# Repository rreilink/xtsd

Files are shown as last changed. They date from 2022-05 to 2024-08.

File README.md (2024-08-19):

XTSD 
====

XTSD is an ISA card that adds an SD-card slot to old PCs using an ISA interface. This project is work in progress.

Repo structure
--------------

| folder | description |
|---|---|
|hardware| Schematic and PCB design in KiCAD |
|hardware-output | Schematic as PDF and Gerber layout files for ordering the PCB |
|GAL | Source and JEDEC binary file for the programmable logic chip U6 (ATF22V10) |

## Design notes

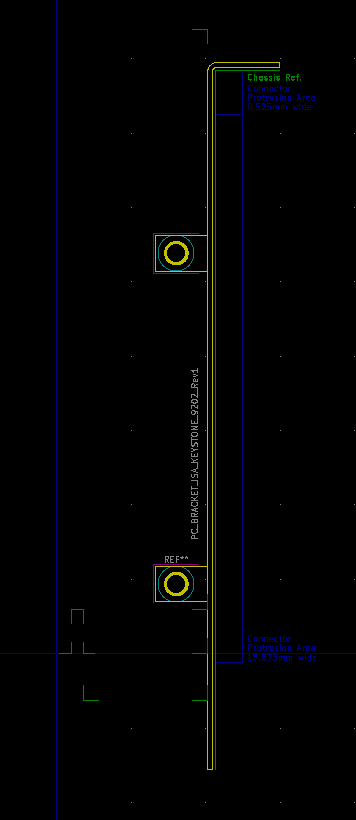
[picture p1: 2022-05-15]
Kicad_Misc-master/Footprints/PC_Bracket_ISA_Keystone_9202/Images/Keystone_9202_Rev1.PNG

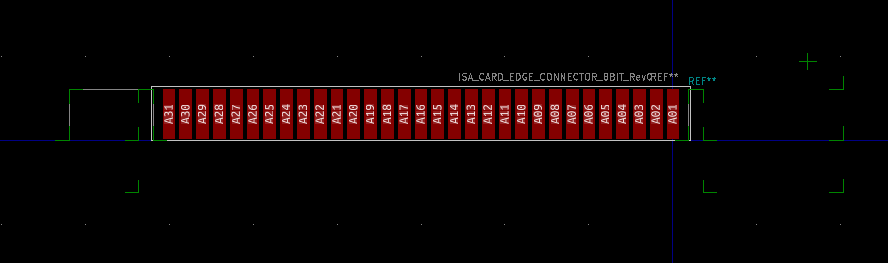
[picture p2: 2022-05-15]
Kicad_Misc-master/Footprints/ISA_Card_Edge_Connector_8bit/Images/ISA_Card_Edge_Connector_8bit_Rev0.PNG

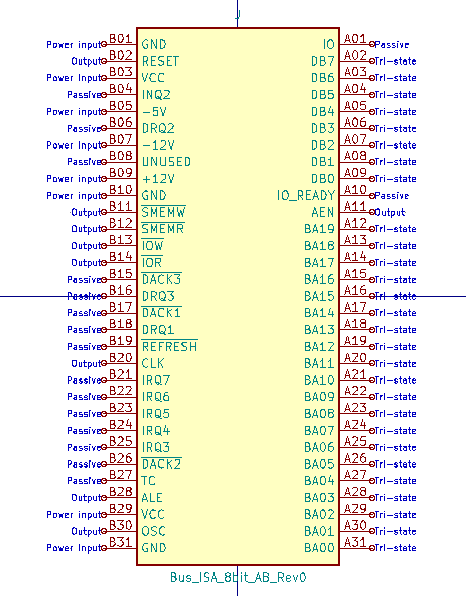
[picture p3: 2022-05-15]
Kicad_Misc-master/Symbols/Bus_ISA_8bit_AB/Images/Bus_ISA_8bit_AB_Rev0.PNG

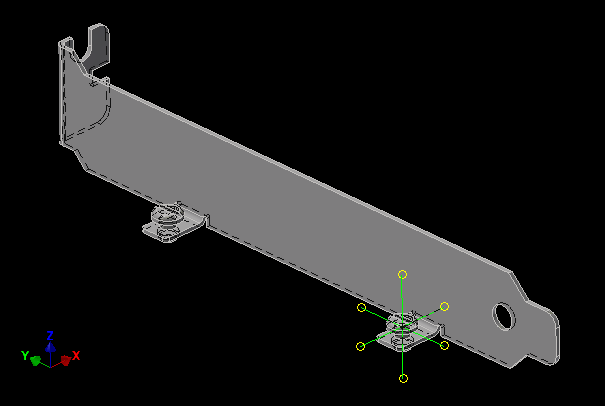
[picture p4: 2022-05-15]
Kicad_Misc-master/3D_Models/Keystone_9202/Images/Keystone_9202_3D_Rev0_1.PNG

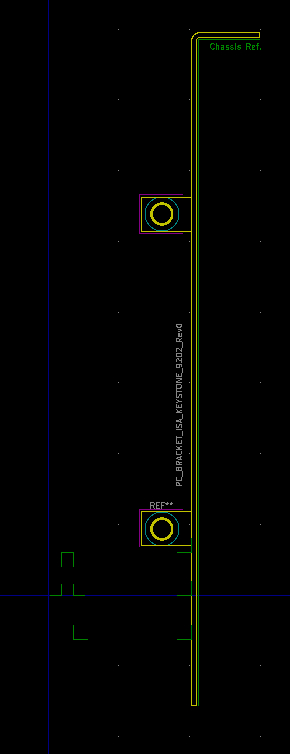
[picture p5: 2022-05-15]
Kicad_Misc-master/Footprints/PC_Bracket_ISA_Keystone_9202/Images/Keystone_9202_Rev0.PNG

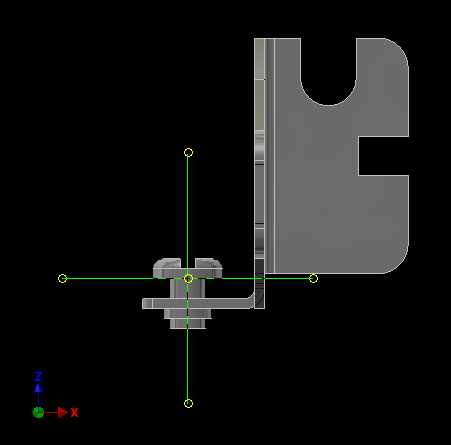
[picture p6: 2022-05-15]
Kicad_Misc-master/3D_Models/Keystone_9202/Images/Keystone_9202_3D_Rev0_2.PNG

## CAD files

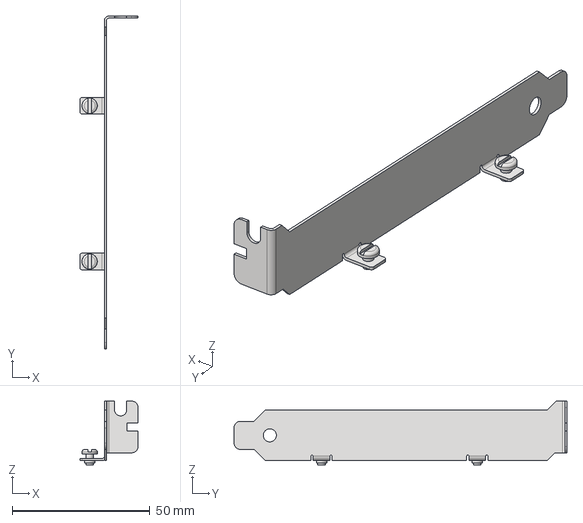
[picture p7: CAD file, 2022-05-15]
Kicad_Misc-master/3D_Models/Keystone_9202/Keystone_9202_Blank.stp
21.1 x 120.8 x 23.2 mm

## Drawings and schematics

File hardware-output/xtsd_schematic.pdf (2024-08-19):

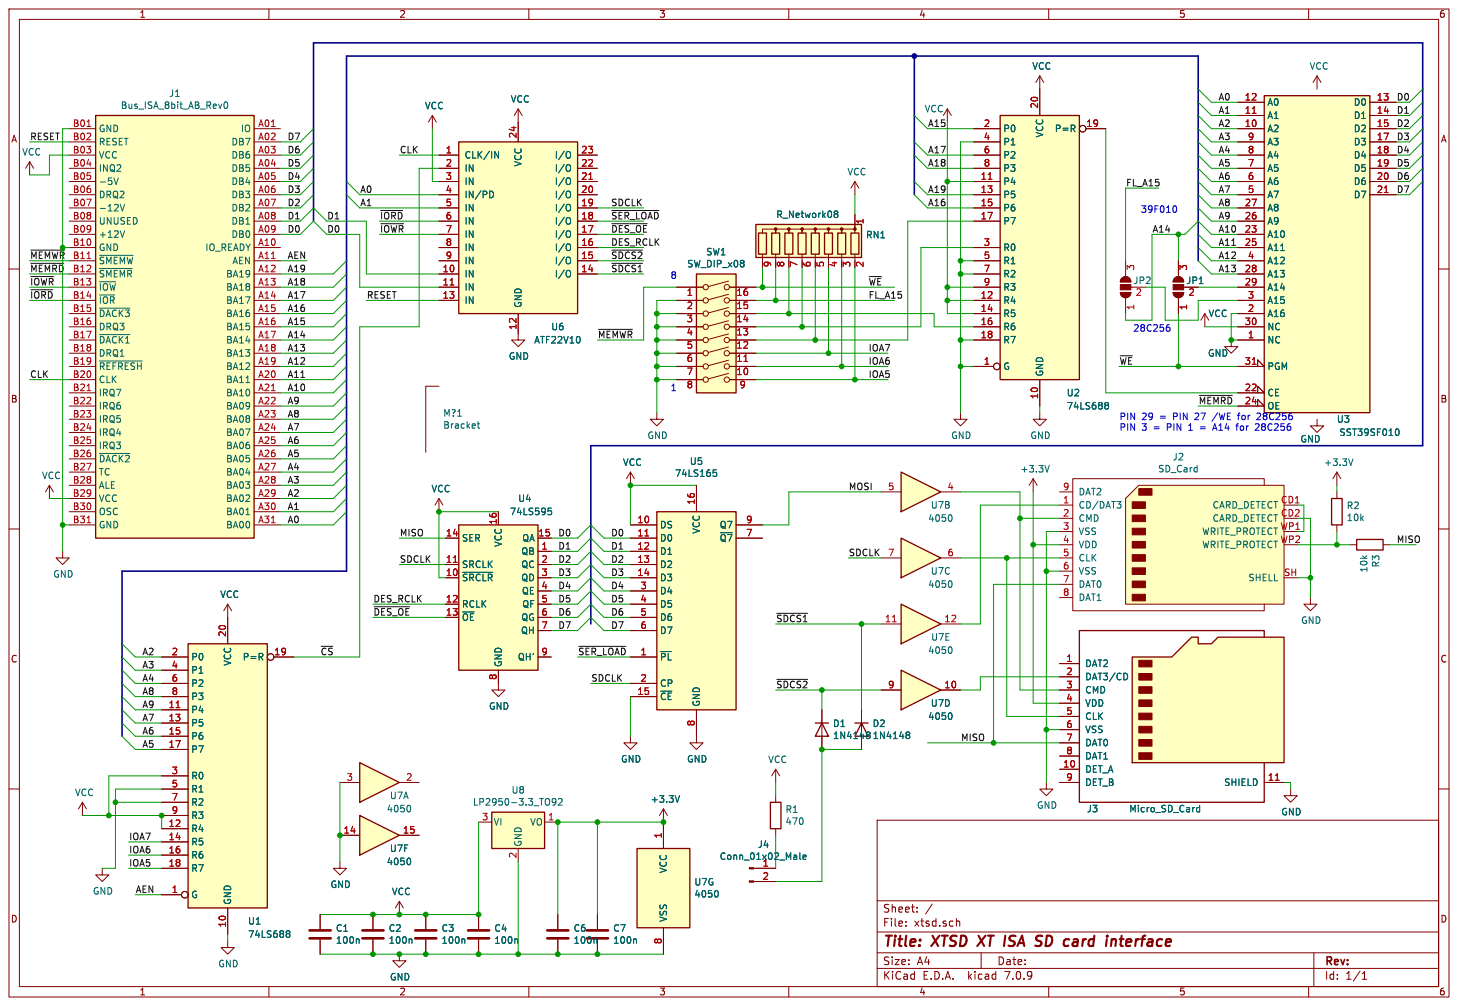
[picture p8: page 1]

J1 Bus_ISA_8bit_AB_Rev0 VCC
IO_READY A10 AEN A11 BA19 A12 BA18 A13 BA17 A14 BA16 A15 BA15 A16 BA14 A17 BA13 A18 BA12 A19 BA11 A20 BA10 A21 BA09 A22 BA08 A23 BA07 A24 BA06 A25 BA05 A26 BA04 A27 BA03 A28 BA02 A29 BA01 A30 BA00 A31 GND B01 RESET B02 VCC B03
-12V B07 UNUSED B08 +12V B09 GND B10 ~{SMEMW} B11 ~{SMEMR} B12 ~{IOW} B13 ~{IOR} B14 ~{DACK3} B15 DRQ3 B16 ~{DACK1} B17 DRQ1 B18 ~{REFRESH} B19 CLK B20

File: xtsd.sch Sheet: /
Id: 1/1 Title: XTSD XT ISA SD card interface

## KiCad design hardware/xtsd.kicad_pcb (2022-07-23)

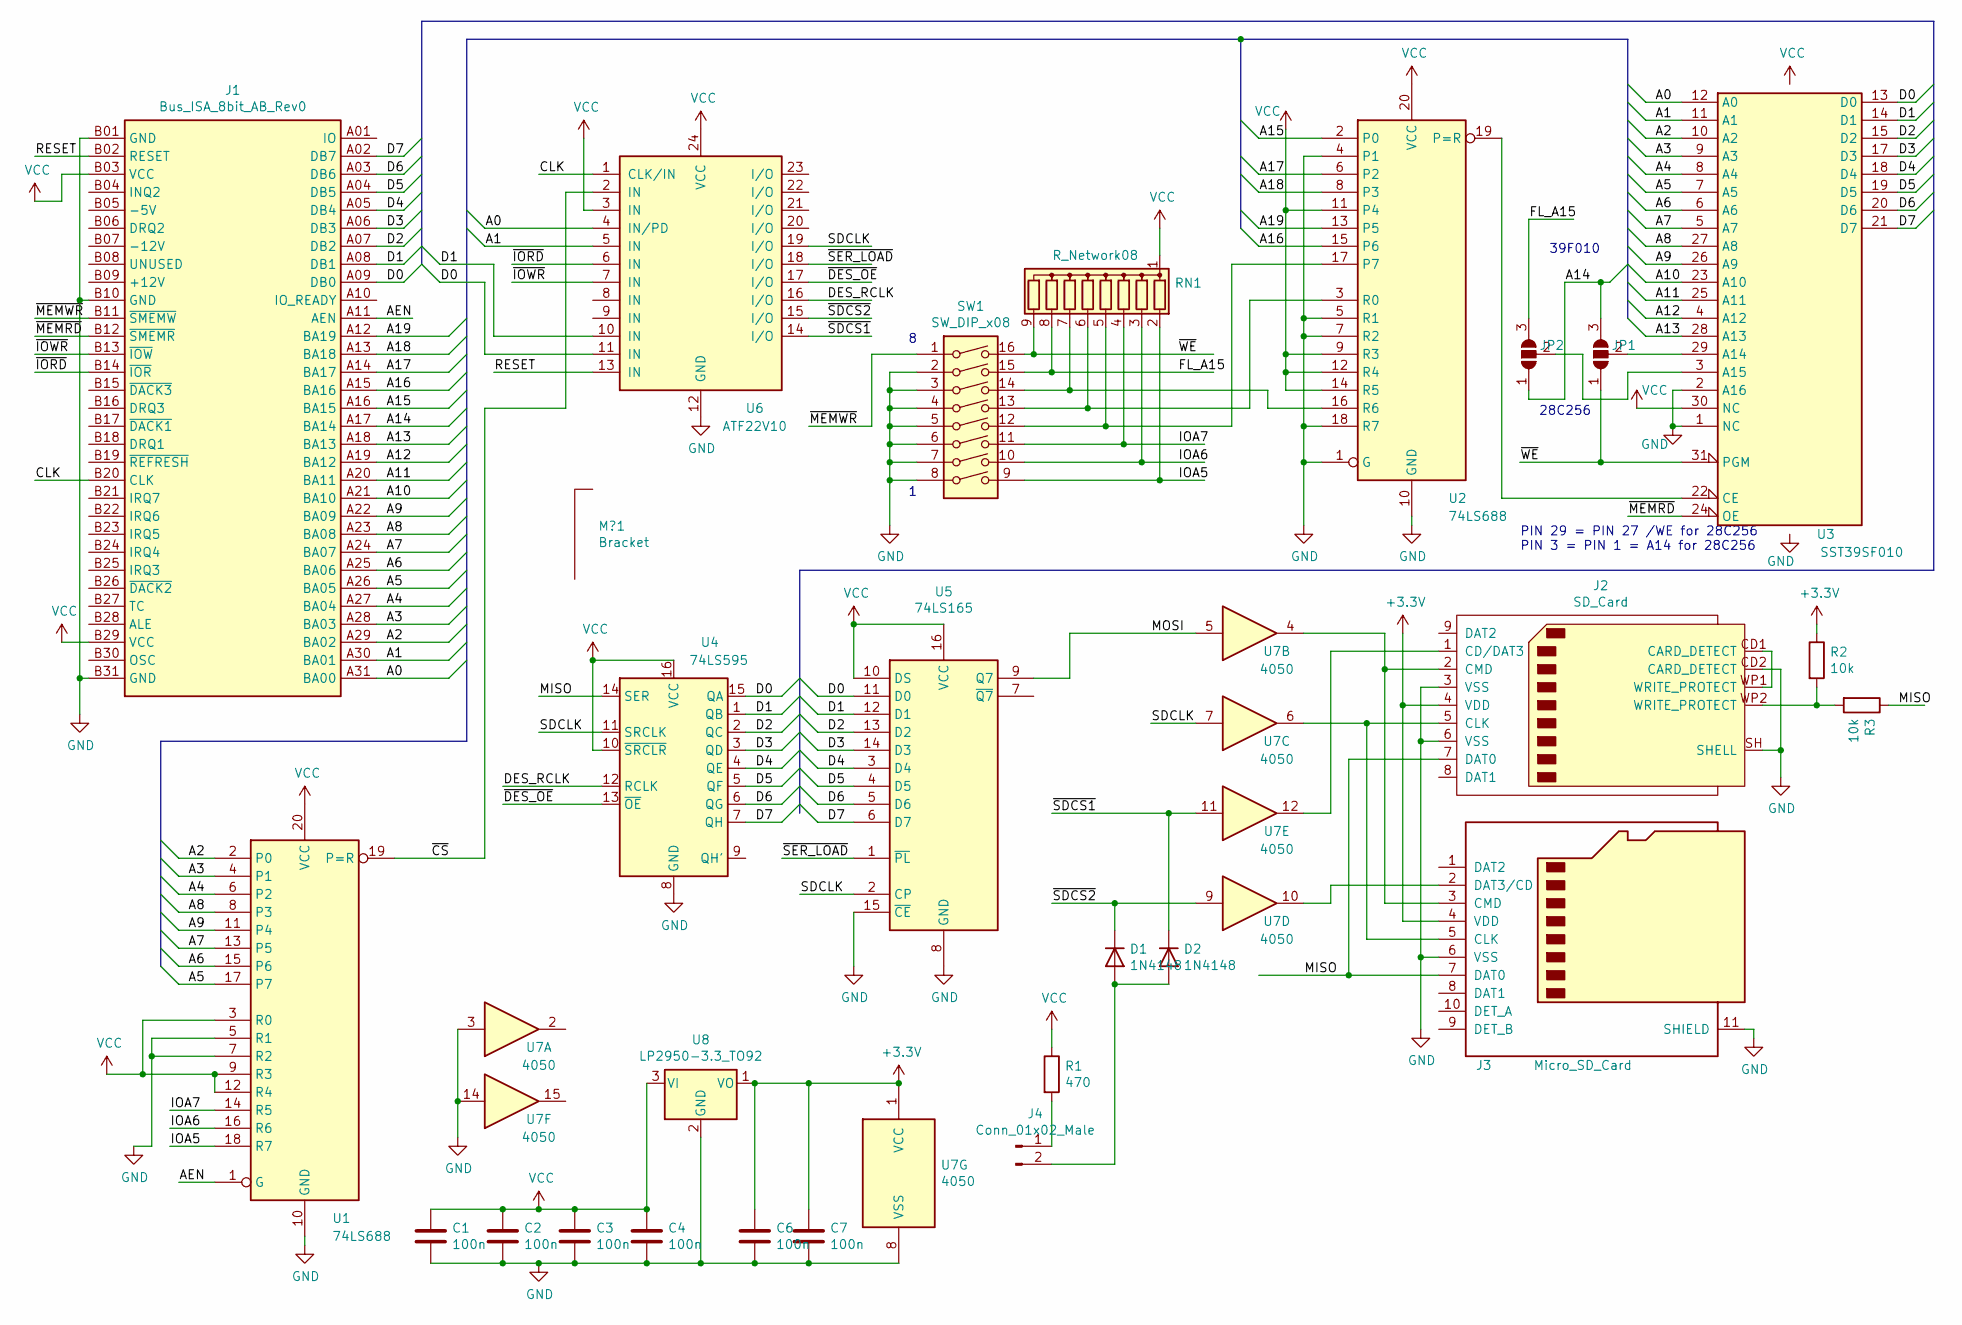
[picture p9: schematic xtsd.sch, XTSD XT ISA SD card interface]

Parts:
C1, C2, C3, C4, C6, C7: 100n; C_Disc_D4.3mm_W1.9mm_P5.00mm
D1, D2: 1N4148; D_DO-35_SOD27_P7.62mm_Horizontal
J1: Bus_ISA_8bit_AB_Rev0; ISA_CARD_EDGE_CONNECTOR_8BIT_Rev1
J2: SD_Card; Molex_503500-0991
J3: Micro_SD_Card; microSD_HC_Molex_104031-0811; Farnell 2678573
J4: Conn_01x02_Male; PinHeader_1x02_P2.54mm_Horizontal
JP1, JP2: SolderJumper_3_Open; SolderJumper-3_P2.0mm_Open_TrianglePad1.0x1.5mm_NumberLabels
M?1: Bracket; PC_BRACKET_ISA_KEYSTONE_9202_Rev1
R1: 470; R_Axial_DIN0207_L6.3mm_D2.5mm_P7.62mm_Horizontal
R2, R3: 10k; R_Axial_DIN0207_L6.3mm_D2.5mm_P7.62mm_Horizontal
RN1: R_Network08; R_Array_SIP9
SW1: SW_DIP_x08; SW_DIP_SPSTx08_Slide_9.78x22.5mm_W7.62mm_P2.54mm
U1, U2: 74LS688; DIP-20_W7.62mm_LongPads
U3: SST39SF010; DIP-32_W15.24mm_Socket_LongPads
U4: 74LS595; DIP-16_W7.62mm_LongPads
U5: 74LS165; DIP-16_W7.62mm_LongPads
U6: ATF22V10; DIP-24_W7.62mm_Socket_LongPads
U7: 4050; DIP-16_W7.62mm_LongPads
U8: LP2950-3.3_TO92; TO-92_Inline

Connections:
+3V3: C6.1, C7.1, J2.4 (VDD), J3.4 (VDD), R2.1, U7.1 (VCC), U8.1 (VO)
/A0: J1.A31 (BA00), U3.12 (A0), U6.4 (IN/PD)
/A1: J1.A30 (BA01), U3.11 (A1), U6.5 (IN)
/A2: J1.A29 (BA02), U1.2 (P0), U3.10 (A2)
/A3: J1.A28 (BA03), U1.4 (P1), U3.9 (A3)
/A4: J1.A27 (BA04), U1.6 (P2), U3.8 (A4)
/A5: J1.A26 (BA05), U1.17 (P7), U3.7 (A5)
/A6: J1.A25 (BA06), U1.15 (P6), U3.6 (A6)
/A7: J1.A24 (BA07), U1.13 (P5), U3.5 (A7)
/A8: J1.A23 (BA08), U1.8 (P3), U3.27 (A8)
/A9: J1.A22 (BA09), U1.11 (P4), U3.26 (A9)
/A10: J1.A21 (BA10), U3.23 (A10)
/A11: J1.A20 (BA11), U3.25 (A11)
/A12: J1.A19 (BA12), U3.4 (A12)
/A13: J1.A18 (BA13), U3.28 (A13)
/A14: J1.A17 (BA14), JP1.3 (B), JP2.1 (A)
/A15: J1.A16 (BA15), U2.2 (P0)
/A16: J1.A15 (BA16), U2.15 (P6)
/A17: J1.A14 (BA17), U2.6 (P2)
/A18: J1.A13 (BA18), U2.8 (P3)
/A19: J1.A12 (BA19), U2.13 (P5)
/AEN: J1.A11 (AEN), U1.1 (G)
/CLK: J1.B20 (CLK), U6.1 (CLK/IN)
/D0: J1.A09 (DB0), U3.13 (D0), U4.15 (QA), U5.11 (D0), U6.11 (IN)
/D1: J1.A08 (DB1), U3.14 (D1), U4.1 (QB), U5.12 (D1), U6.10 (IN)
/D2: J1.A07 (DB2), U3.15 (D2), U4.2 (QC), U5.13 (D2)
/D3: J1.A06 (DB3), U3.17 (D3), U4.3 (QD), U5.14 (D3)
/D4: J1.A05 (DB4), U3.18 (D4), U4.4 (QE), U5.3 (D4)
/D5: J1.A04 (DB5), U3.19 (D5), U4.5 (QF), U5.4 (D5)
/D6: J1.A03 (DB6), U3.20 (D6), U4.6 (QG), U5.5 (D6)
/D7: J1.A02 (DB7), U3.21 (D7), U4.7 (QH), U5.6 (D7)
/DES_RCLK: U4.12 (RCLK), U6.16 (I/O)
/FL_A15: JP2.3 (B), RN1.8 (R7), SW1.15
/IOA5: RN1.2 (R1), SW1.9, U1.18 (R7)
/IOA6: RN1.3 (R2), SW1.10, U1.16 (R6)
/IOA7: RN1.4 (R3), SW1.11, U1.14 (R5)
/MISO: J2.7 (DAT0), J3.7 (DAT0), R3.1, U4.14 (SER)
/MOSI: U5.9 (Q7), U7.5
/RESET: J1.B02 (RESET), U6.13 (IN)
/SDCLK: U4.11 (SRCLK), U5.2 (CP), U6.19 (I/O), U7.7
/~CS~: U1.19 (P=R), U6.2 (IN)
/~DES_OE~: U4.13 (~OE), U6.17 (I/O)
/~IORD~: J1.B14 (~IOR), U6.6 (IN)
/~IOWR~: J1.B13 (~IOW), U6.7 (IN)
/~MEMRD~: J1.B12 (~SMEMR), U3.24 (OE)
/~MEMWR~: J1.B11 (~SMEMW), SW1.1
/~SDCS1~: D2.1 (K), U6.14 (I/O), U7.11
/~SDCS2~: D1.1 (K), U6.15 (I/O), U7.9
/~SER_LOAD~: U5.1 (~PL), U6.18 (I/O)
/~WE~: JP1.1 (A), RN1.9 (R8), SW1.16, U3.31 (PGM)
GND: C1.2, C2.2, C3.2, C4.2, C6.2, C7.2, J1.B01 (GND), J1.B10 (GND), J1.B31 (GND), J2.3 (VSS), J2.6 (VSS), J2.CD2 (CARD_DETECT), J2.SH (SHELL), J3.6 (VSS), J3.11 (SHIELD), SW1.2, SW1.3, SW1.4, SW1.5, SW1.6, SW1.7, SW1.8, U1.5 (R1), U1.7 (R2), U1.10 (GND), U2.1 (G), U2.4 (P1), U2.5 (R1), U2.7 (R2), U2.10 (GND), U2.18 (R7), U3.1 (NC), U3.2 (A16), U3.16 (GND), U4.8 (GND), U5.8 (GND), U5.15 (~CE), U6.12 (GND), U7.3, U7.8 (VSS), U7.14, U8.2 (GND)
unnamed: D1.2 (A), D2.2 (A), J4.2
unnamed: J2.1 (CD/DAT3), U7.12
unnamed: J2.2 (CMD), J3.3 (CMD), U7.4
unnamed: J2.5 (CLK), J3.5 (CLK), U7.6
unnamed: J2.CD1 (CARD_DETECT), J2.WP1 (WRITE_PROTECT)
unnamed: J2.WP2 (WRITE_PROTECT), R2.2, R3.2
unnamed: J3.2 (DAT3/CD), U7.10
unnamed: J4.1, R1.2
unnamed: JP1.2 (C), U3.29 (A14)
unnamed: JP2.2 (C), U3.3 (A15)
unnamed: RN1.5 (R4), SW1.12, U2.17 (P7)
unnamed: RN1.6 (R5), SW1.13, U2.3 (R0)
unnamed: RN1.7 (R6), SW1.14, U2.16 (R6)
unnamed: U2.19 (P=R), U3.22 (CE)
VCC: C1.1, C2.1, C3.1, C4.1, J1.B03 (VCC), J1.B29 (VCC), R1.1, RN1.1 (common), U1.3 (R0), U1.9 (R3), U1.12 (R4), U1.20 (VCC), U2.9 (R3), U2.11 (P4), U2.12 (R4), U2.14 (R5), U2.20 (VCC), U3.30 (NC), U3.32 (VCC), U4.10 (~SRCLR), U4.16 (VCC), U5.10 (DS), U5.16 (VCC), U6.3 (IN), U6.24 (VCC), U8.3 (VI)

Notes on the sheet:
PIN 29 = PIN 27 /WE for 28C256 PIN 3 = PIN 1 = A14 for 28C256
28C256
39F010

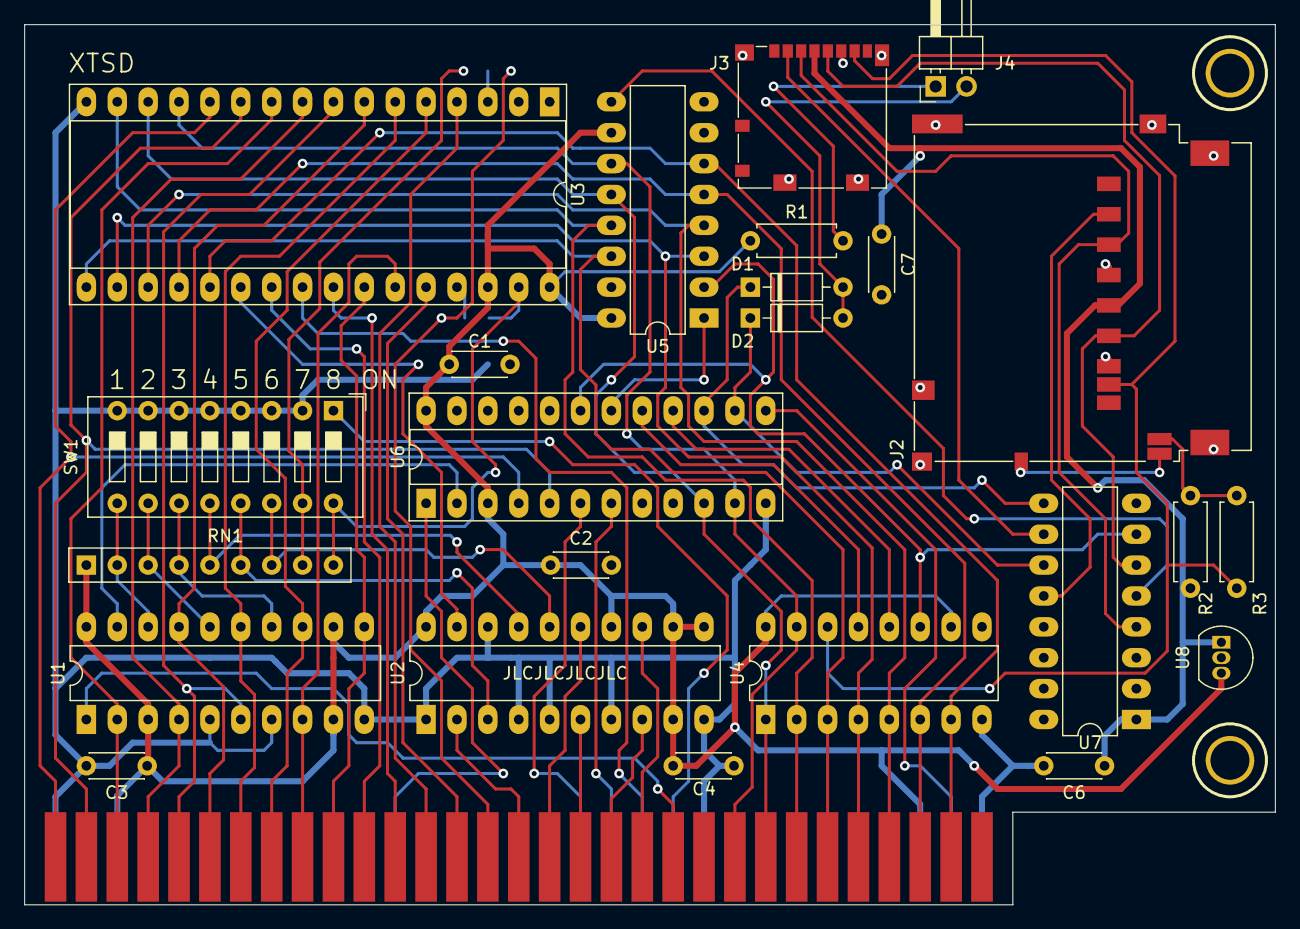
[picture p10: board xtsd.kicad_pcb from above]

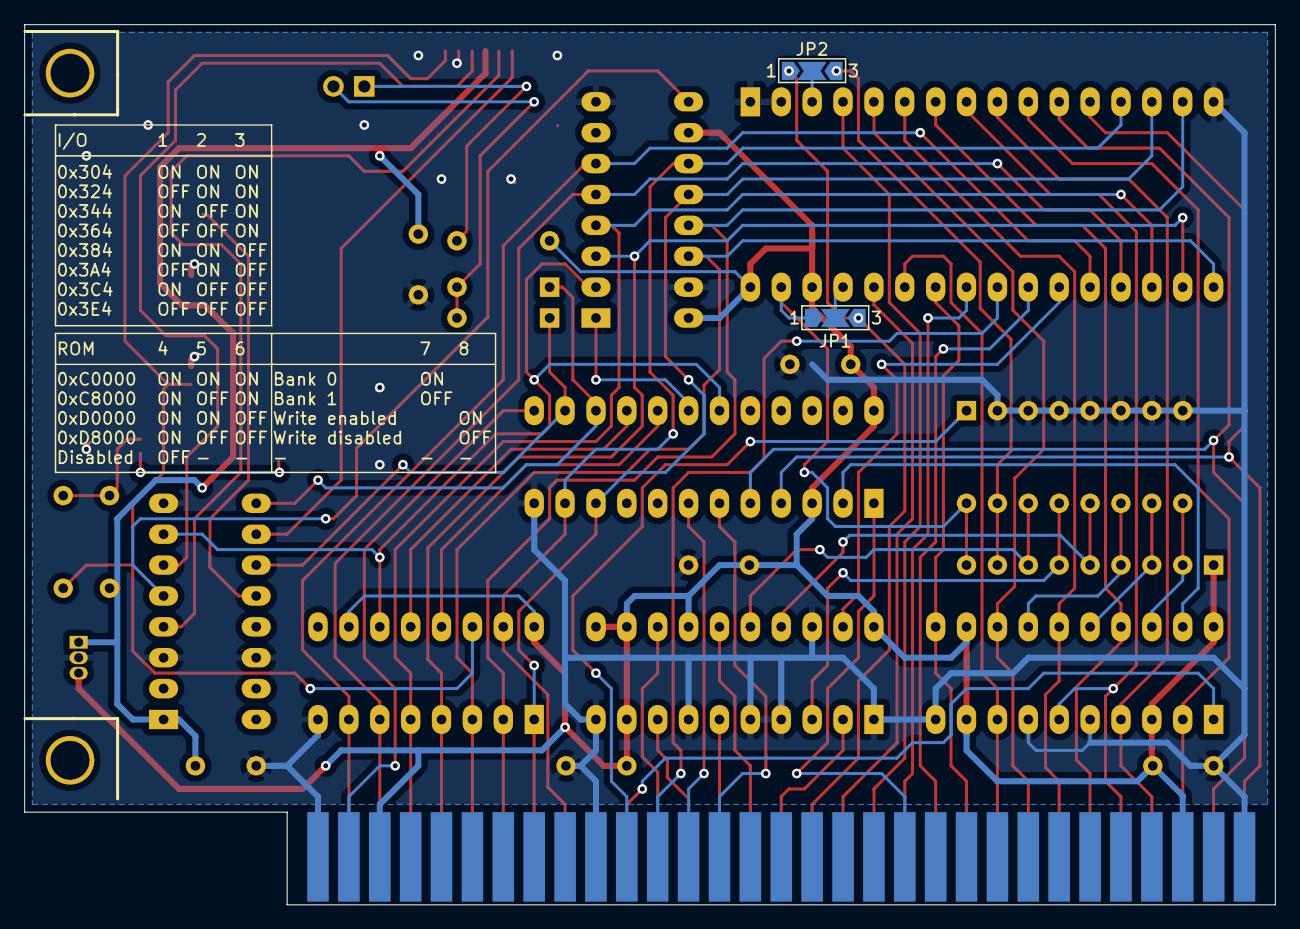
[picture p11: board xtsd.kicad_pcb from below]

Board: 2 copper layers, 102.9 x 72.4 mm, 28 parts (2 on the bottom side), 66 nets.

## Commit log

2022-05-15 Initial import
    [Keystone_9202_Blank.stp, xtsd.kicad_pcb, xtsd.sch]
2022-05-15 As ordered
    [xtsd-B_Cu.gbl, xtsd-B_Mask.gbs, xtsd-B_Paste.gbp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]
2022-07-23 fix: U4 /SRCLR should be connected to VCC instead of GND
    [xtsd.kicad_pcb, xtsd.sch]
2024-08-19 Added GAL source and JEDEC file; added schematic as PDF
